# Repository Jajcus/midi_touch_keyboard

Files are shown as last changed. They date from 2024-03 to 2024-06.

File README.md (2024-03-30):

# MIDI Touch Keyboard

**Disclaimer**: this is a one-time personal hobby project. Shared as-is. Work
in progress. **Use at your own risk**, if at all.

This project is a device that lets you play MIDI synthesizer by touching
conducting surfaces, like fruits or vegetables.

It has 16 inputs (a bit over an octave), standard DIN-5 MIDI output and USB
MIDI interface. Additional controls include 'calibrate' button and a
'sensitivity' potentiometer.

A LED strip provides additional feedback displaying key state in piano-like layout.

assembled and connected
device with fruits and veggies connected

## Working principle

Each 'input' is a simple capacitive sensor. Touching it either significantly
increases input capacitance or lowers its resistance to the device's ground. In
both cases this causes increase in the time constant of an RC circuit monitored
by a microcontroller.

The microcontroller charges the capacitance of the sensor circuit in short
intervals and checks if it discharges before a specific time. If it does, then
the input is open if it does not, it means the sensor has been touched.

The time to wait for discharging is determined through a calibration process
and the sensitivity potentiometer. The calibration process just measures the discharge times,
and collects maximum and minimum values measured, to roughly find the threshold
range. This assumes that at least one of the sensors has been touched during calibration.
Then the sensitivity knob can be used to set threshold within this range.

## Circuit design

The heart of the device is a Raspberry Pi Pico board. Cheap and powerful enough.

The sensor inputs are built using two resistors and a capacitor connected do
the microcontroller general-purpose IO pins. Values of those components has
been chosen experimentally to get quick and precise-enough measurements.

One pin is used to drive MIDI output. That is a standard circuit from the MIDI
1.0 specification using a transistor as the current loop switch (with a
Schottky diode for sharper edges).

Another pin drives addressable LED strip (WS2812B). Again, a transistor with a
Schottky diode is used to drive 5V data line here.

Two pins are used for button (actually only one used at the moment).

One ADC pin is connected to the sensitivity potentiometer. Another ADC pin is
connected to the sensors connector, so it can be used for detection of a device
connected there (in case I make one).

There is also an additional DC input, in case the micro-USB on the Pico is not
enough, because why not.

circuit schematic

## Hardware realization

The device has been built on a single 'DIY' double-sided PCB, manufactured on a
small CNC engraver. Brass rivets are used for vias, otherwise no holes are
copper-plated. Most elements are surface mounted, 0603 size. The Raspberry Pi
Pico board is also surface-soldered to the main PCB, to keep overall low
profile (which the MIDI jack breaks anyway).

Sensor inputs are available via an angled 2x20 pin connector (like for an
old-style IDE HDD ribbon). Lower pins are all ground, sensors are on the upper
pins, starting from the third one. The last upper pin measures resistance to
the ground, for some auto-configuration capability in the future (not used now).

PCB layout is designed for my DIY constraints and the way I imagined the
complete device and is not suitable for most other fabrication processes.

The PCB design from KiCAD has been exported to Gerber files which would first
be converted to gcode by [pcb2gcode](https://github.com/pcb2gcode/pcb2gcode)
and then that gcode would be further processed by my
[postprocess.py](kicad/postprocess.py) script, for easier use with
[bCNC](https://github.com/vlachoudis/bCNC). Then couple of attempts and many
hours with the CNC machine and the PCB was ready for soldering. No soldermask,
unfortunately.

Even without the soldermask and with the small SMD components soldering was not
very hard. There was just a couple places that needed a do-over and proper
cleanup (the sensor circuit is quite sensitive to bad isolation, as 10 megaohm
resistors are used there).

The holes were drilled a bit to shallow, but that was not hard to fix, either.

PCB tracks close up
PCB holes top view
PCB holes bottom view
via rivets top view
small parts soldered

## Firmware

The firmware is written in Rust, using the marvelous
[Embassy](https://embassy.dev/) framework. Nothing fancy otherwise.

One CPU core is dedicated for reading the sensors and UI inputs and basic
key-on/key-off logic. The other core does MIDI I/O over serial and USB.
Components communicate by passing messages via Embassy channels.

The LED strip programming uses Raspberry Pi Pico's PIO (programmable I/O), so
no bit-banging in CPU time is needed.

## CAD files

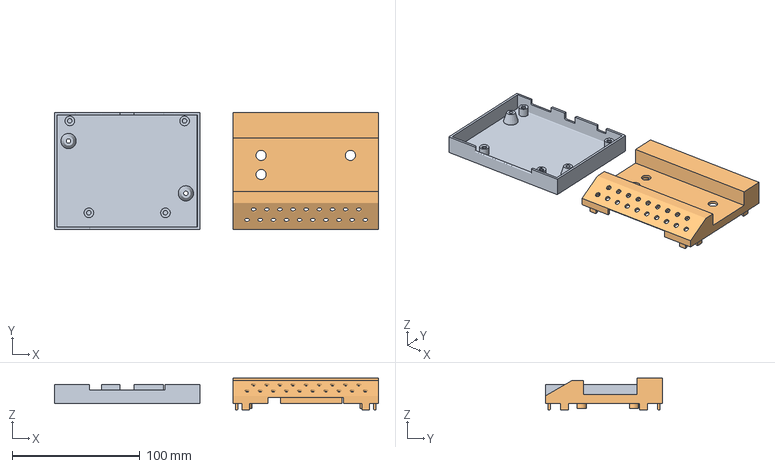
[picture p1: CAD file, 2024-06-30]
case/tk_case_3dprint.FCStd
254.0 x 92.0 x 25.0 mm
Case Bottom (Meshed)
Case Top (Meshed)

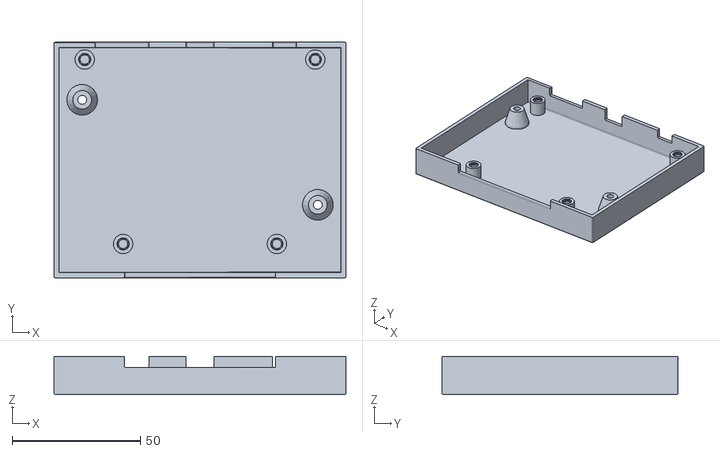
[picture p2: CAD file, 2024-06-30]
case/tk_case_bottom.stl
114.0 x 92.0 x 15.0

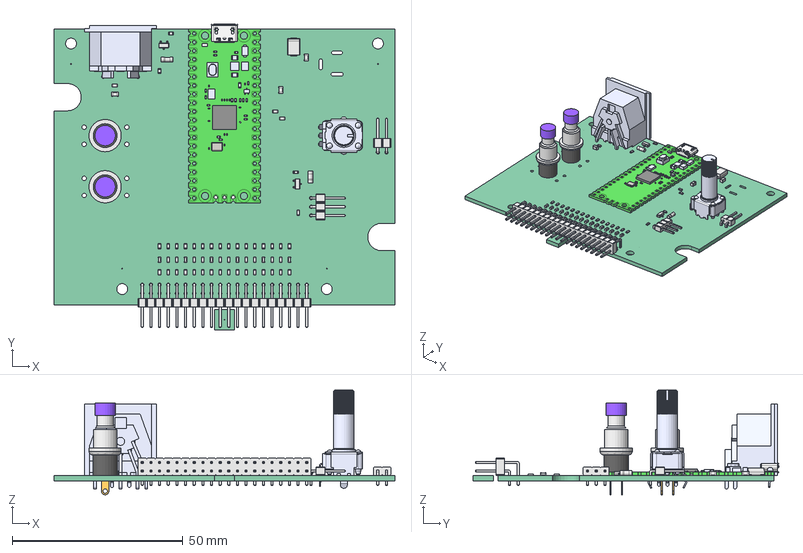
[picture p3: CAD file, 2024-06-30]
case/touch_keyboard_pcb.FCStd
100.0 x 89.7 x 30.7 mm
Pcb_1056
R33_R_0603_1608Metric_b52117b7a5b0 x 39
C5_C_0603_1608Metric_656f8ebd2c8c x 16
C18_C_0805_2012Metric_1ea8b0f87ad5 x 3
PCB, Raspberry Pi Pico-R3
MicroUSB Port, Raspberry Pi Pico-R3
MicroUSB Port, Raspberry Pi Pico-R004
MicroUSB Port, Raspberry Pi Pico-R005
MicroUSB Port, Raspberry Pi Pico-R006
MicroUSB Port, Raspberry Pi Pico-R007
MicroUSB Port, Raspberry Pi Pico-R008
MicroUSB Port, Raspberry Pi Pico-R009
RP2040 Microcontroller, Raspberry Pi Pico-R3
SW1, Tact Switch, Raspberry Pi Pico-R3
D1, Diode, Schottky, Raspberry Pi Pico-R3
D2, QSME-C194, LED, Raspberry Pi Pico-R3
L1, Inductor, Raspberry Pi Pico-R3
U2, RT6150B-33GQW, Buck Boost Converter, Raspberry Pi Pico-R3
U3, W25Q16JVUXIQ, Serial NOR Flash 16 Mbit, Raspberry Pi Pico-R3
Q1, MOSFET, DMG1012T, Raspberry Pi Pico-R3
X1, X12M000000S096, 12 Mhz Crystal Resonator, Raspberry Pi Pico-R3
SMD Resistor, Configurable, Raspberry Pi Pico-R3_R1
SMD Resistor, Configurable, Raspberry Pi Pico-R3_R002
SMD Resistor, Configurable, Raspberry Pi Pico-R3_R003
SMD Resistor, Configurable, Raspberry Pi Pico-R3_R2
SMD Resistor, Configurable, Raspberry Pi Pico-R3_R005
SMD Resistor, Configurable, Raspberry Pi Pico-R3_R006
SMD Resistor, Configurable, Raspberry Pi Pico-R3_R3
SMD Resistor, Configurable, Raspberry Pi Pico-R3_R008
SMD Resistor, Configurable, Raspberry Pi Pico-R3_R009
SMD Resistor, Configurable, Raspberry Pi Pico-R3_R4
SMD Resistor, Configurable, Raspberry Pi Pico-R3_R011
SMD Resistor, Configurable, Raspberry Pi Pico-R3_R012
SMD Resistor, Configurable, Raspberry Pi Pico-R3_R5
SMD Resistor, Configurable, Raspberry Pi Pico-R3_R014
SMD Resistor, Configurable, Raspberry Pi Pico-R3_R015
SMD Resistor, Configurable, Raspberry Pi Pico-R3_R6
SMD Resistor, Configurable, Raspberry Pi Pico-R3_R017
SMD Resistor, Configurable, Raspberry Pi Pico-R3_R018
SMD Resistor, Configurable, Raspberry Pi Pico-R3_R7
SMD Resistor, Configurable, Raspberry Pi Pico-R3_R020
SMD Resistor, Configurable, Raspberry Pi Pico-R3_R021
SMD Resistor, Configurable, Raspberry Pi Pico-R3_R8
SMD Resistor, Configurable, Raspberry Pi Pico-R3_R023
SMD Resistor, Configurable, Raspberry Pi Pico-R3_R024
SMD Resistor, Configurable, Raspberry Pi Pico-R3_R9
SMD Resistor, Configurable, Raspberry Pi Pico-R3_R026
SMD Resistor, Configurable, Raspberry Pi Pico-R3_R027
SMD Resistor, Configurable, Raspberry Pi Pico-R3_R10
SMD Resistor, Configurable, Raspberry Pi Pico-R3_R029
SMD Resistor, Configurable, Raspberry Pi Pico-R3_R030
SMD Resistor, Configurable, Raspberry Pi Pico-R3_R11
SMD Resistor, Configurable, Raspberry Pi Pico-R3_R032
SMD Resistor, Configurable, Raspberry Pi Pico-R3_R033
SMD Resistor, Configurable, Raspberry Pi Pico-R3_R12
SMD Resistor, Configurable, Raspberry Pi Pico-R3_R035
SMD Resistor, Configurable, Raspberry Pi Pico-R3_R036
SMD Resistor, Configurable, Raspberry Pi Pico-R3_R13
SMD Resistor, Configurable, Raspberry Pi Pico-R3_R038
SMD Resistor, Configurable, Raspberry Pi Pico-R3_R039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

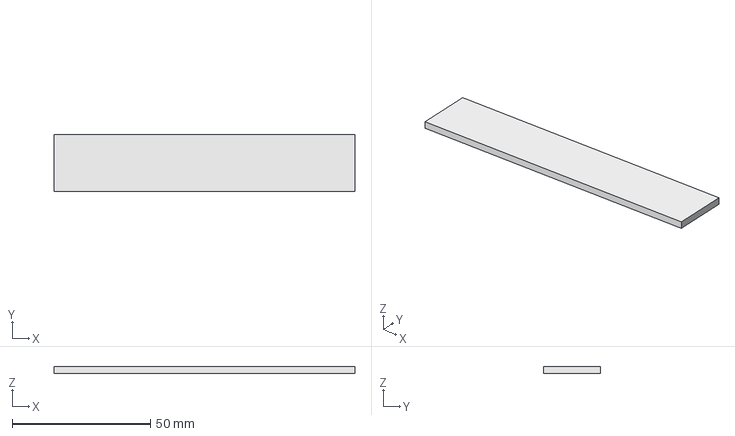
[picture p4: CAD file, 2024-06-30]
case/touch_keyboard_led_strip.FCStd
109.0 x 20.5 x 2.50 mm

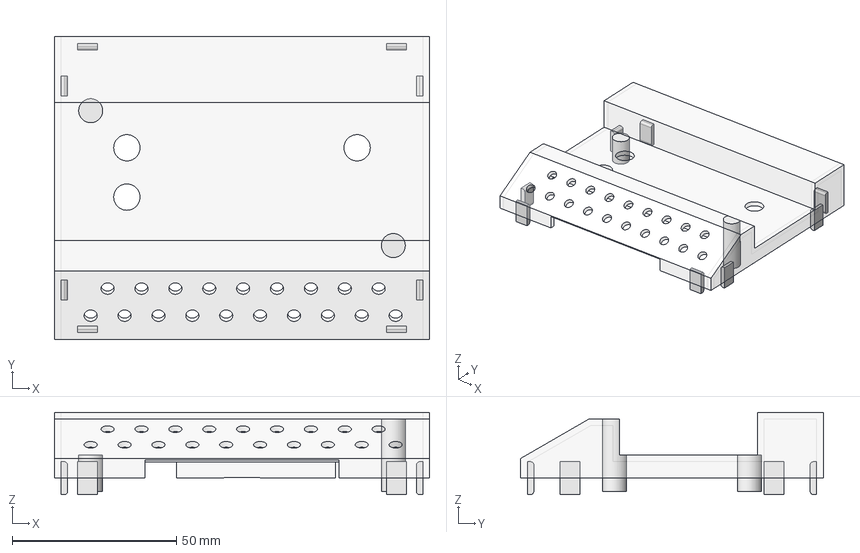
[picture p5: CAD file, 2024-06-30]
case/touch_keyboard_case_top.FCStd
114.0 x 92.0 x 25.0 mm
Case Top Body
Post1
Post2
Tab1
Tab2
Tab3
Tab4
Tab5
Tab6
Tab7
Tab8

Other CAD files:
case/touch_keyboard_case.FCStd
case/touch_keyboard_case_bottom.FCStd
case/tk_case_top.stl

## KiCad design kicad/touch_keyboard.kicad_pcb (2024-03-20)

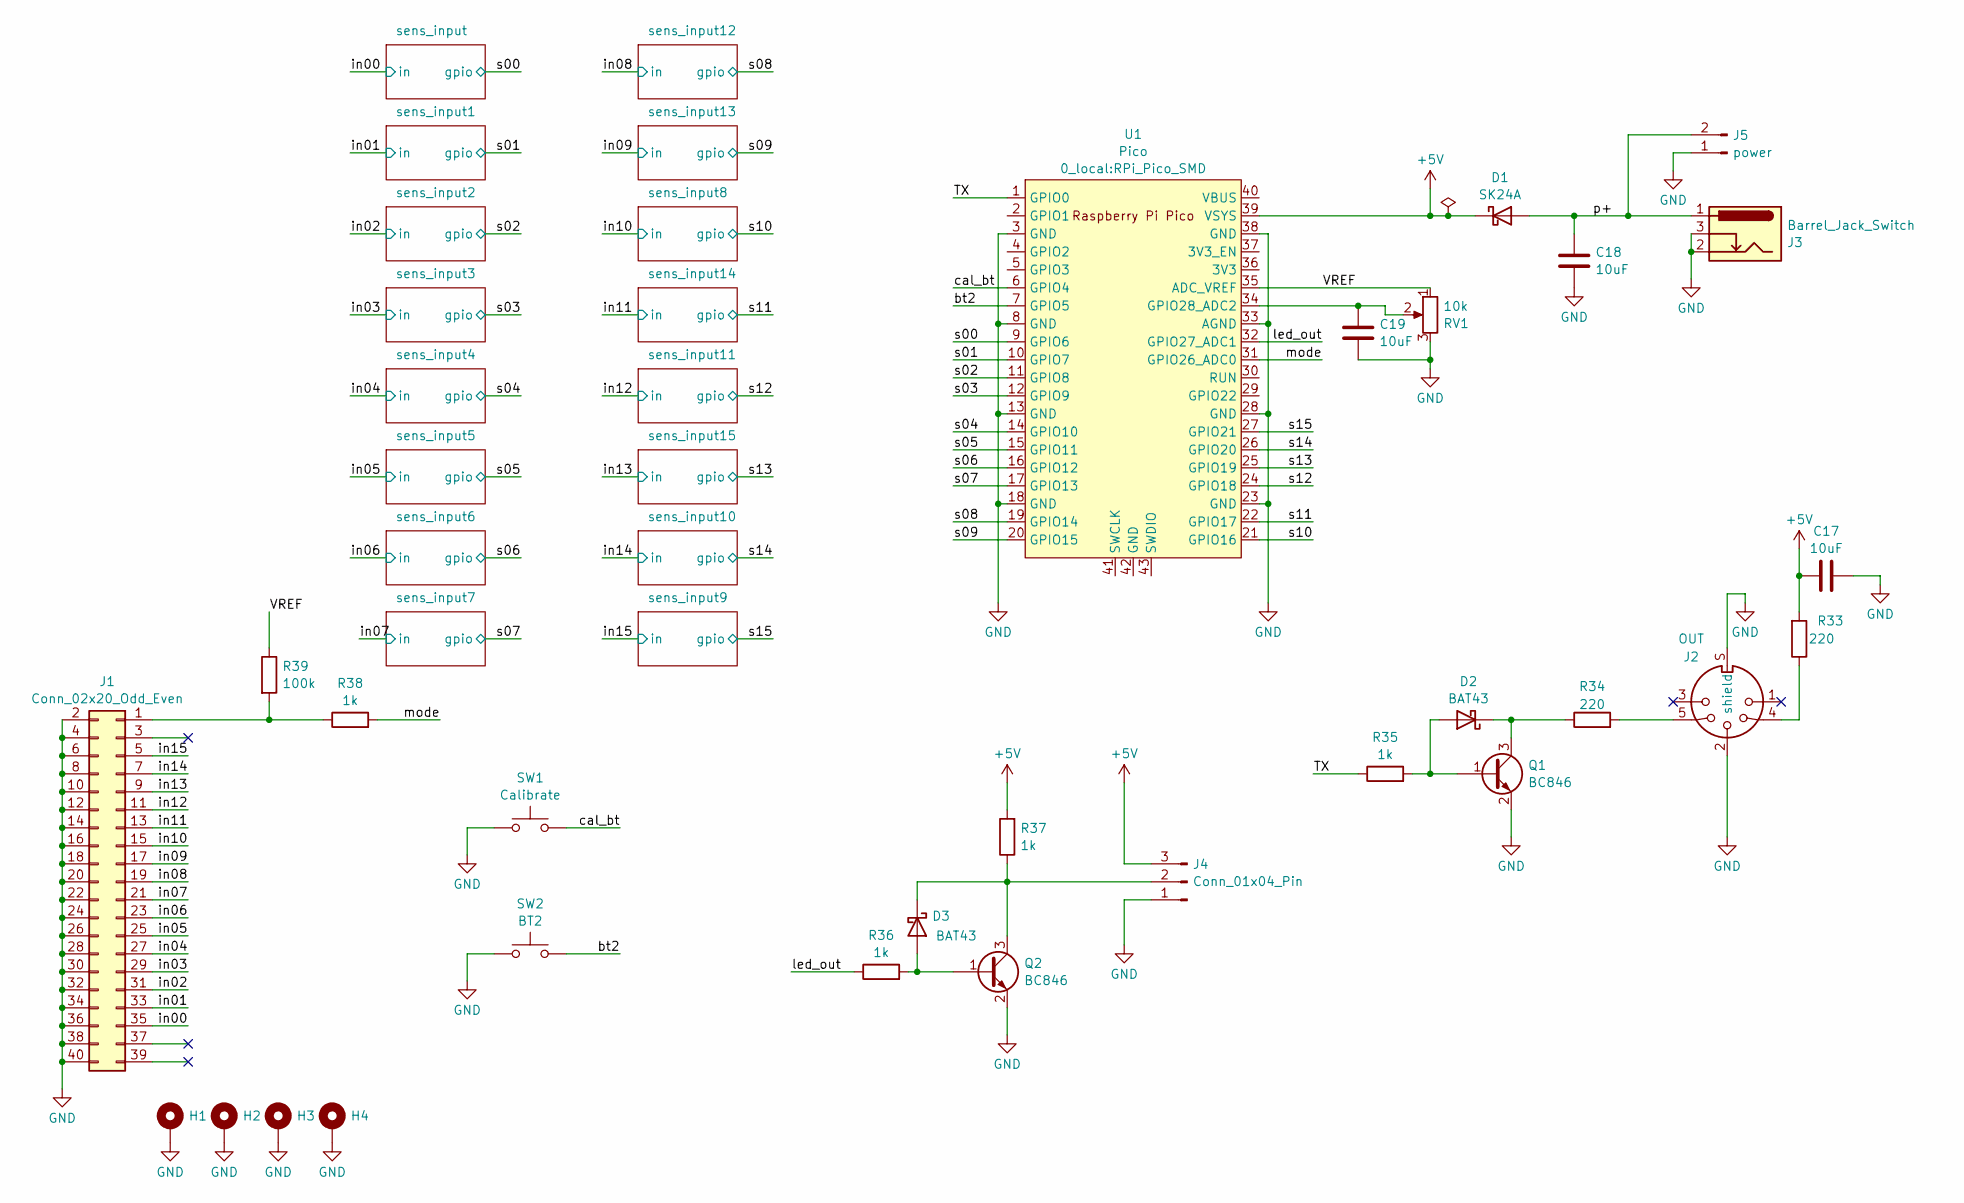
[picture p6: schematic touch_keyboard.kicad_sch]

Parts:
C17, C18, C19: 10uF; C_0805_2012Metric
D1: SK24A; D_SMA-SMB_Universal_Handsoldering
D2, D3: BAT43; D_MiniMELF
H1, H2, H3, H4: MountingHole_Pad; MountingHole_3.2mm_M3_DIN965_Pad
J1: Conn_02x20_Odd_Even; PinHeader_2x20_P2.54mm_Horizontal
J2: OUT; DIN_5
J3: Barrel_Jack_Switch; BarrelJack_CUI_PJ-063AH_Horizontal
J4: Conn_01x04_Pin; PinHeader_1x03_P2.54mm_Horizontal
J5: power; PinHeader_1x02_P2.54mm_Horizontal
Q1, Q2: BC846; SOT-23
R33, R34: 220; R_0603_1608Metric; MPN C22962
R35, R36, R37, R38: 1k; R_0603_1608Metric; MPN C22962
R39: 100k; R_0603_1608Metric; MPN C22962
RV1: 10k; Potentiometer_Bourns_PTV09A-1_Single_Vertical
SW1: Calibrate; Button
SW2: BT2; Button
U1: Pico; RPi_Pico_SMD

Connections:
+5V: C17.1, D1.1 (K), J4.3, R33.2, R37.2, U1.39 (VSYS)
/TX: R35.1, U1.1 (GPIO0)
/VREF: R39.1, RV1.1, U1.35 (ADC_VREF)
/bt2: SW2.2, U1.7 (GPIO5)
/cal_bt: SW1.2, U1.6 (GPIO4)
/in00: J1.35; also elsewhere on the board
/in01: J1.33; also elsewhere on the board
/in02: J1.31; also elsewhere on the board
/in03: J1.29; also elsewhere on the board
/in04: J1.27; also elsewhere on the board
/in05: J1.25; also elsewhere on the board
/in06: J1.23; also elsewhere on the board
/in07: J1.21; also elsewhere on the board
/in08: J1.19; also elsewhere on the board
/in09: J1.17; also elsewhere on the board
/in10: J1.15; also elsewhere on the board
/in11: J1.13; also elsewhere on the board
/in12: J1.11; also elsewhere on the board
/in13: J1.9; also elsewhere on the board
/in14: J1.7; also elsewhere on the board
/in15: J1.5; also elsewhere on the board
/led_out: R36.1, U1.32 (GPIO27_ADC1)
/mode: R38.2, U1.31 (GPIO26_ADC0)
/p+: C18.2, D1.2 (A), J3.1, J5.2
/s00: U1.9 (GPIO6); also elsewhere on the board
/s01: U1.10 (GPIO7); also elsewhere on the board
/s02: U1.11 (GPIO8); also elsewhere on the board
/s03: U1.12 (GPIO9); also elsewhere on the board
/s04: U1.14 (GPIO10); also elsewhere on the board
/s05: U1.15 (GPIO11); also elsewhere on the board
/s06: U1.16 (GPIO12); also elsewhere on the board
/s07: U1.17 (GPIO13); also elsewhere on the board
/s08: U1.19 (GPIO14); also elsewhere on the board
/s09: U1.20 (GPIO15); also elsewhere on the board
/s10: U1.21 (GPIO16); also elsewhere on the board
/s11: U1.22 (GPIO17); also elsewhere on the board
/s12: U1.24 (GPIO18); also elsewhere on the board
/s13: U1.25 (GPIO19); also elsewhere on the board
/s14: U1.26 (GPIO20); also elsewhere on the board
/s15: U1.27 (GPIO21); also elsewhere on the board
GND: C17.2, C18.1, C19.1, H1.1, H2.1, H3.1, H4.1, J1.2, J1.4, J1.6, J1.8, J1.10, J1.12, J1.14, J1.16, J1.18, J1.20, J1.22, J1.24, J1.26, J1.28, J1.30, J1.32, J1.34, J1.36, J1.38, J1.40, J2.2, J2.S (shield), J3.2, J3.3, J4.1, J5.1, Q1.2 (E), Q2.2 (E), RV1.3, SW1.1, SW2.1, U1.3 (GND), U1.8 (GND), U1.13 (GND), U1.18 (GND), U1.23 (GND), U1.28 (GND), U1.33 (AGND), U1.38 (GND); also elsewhere on the board
unnamed: D2.2 (A), Q1.1 (B), R35.2
unnamed: D2.1 (K), Q1.3 (C), R34.1
unnamed: D3.2 (A), Q2.1 (B), R36.2
unnamed: D3.1 (K), J4.2, Q2.3 (C), R37.1
unnamed: J1.1, R38.1, R39.2
unnamed: J2.4, R33.1
unnamed: J2.5, R34.2
unnamed: C19.2, RV1.2, U1.34 (GPIO28_ADC2)

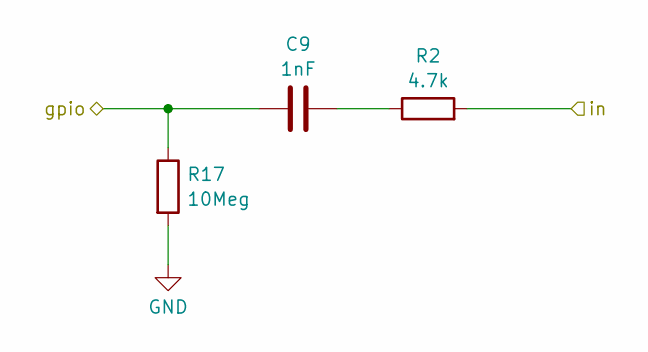
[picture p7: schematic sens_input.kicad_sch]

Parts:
C9: 1nF; C_0603_1608Metric
R2: 4.7k; R_0603_1608Metric
R17: 10Meg; R_0603_1608Metric

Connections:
/in00: R2.2; also elsewhere on the board
/s08: C9.1, R17.1; also elsewhere on the board
GND: R17.2; also elsewhere on the board

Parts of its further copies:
C1, C2, C3, C4, C5, C6, C7, C8, C10, C11, C12, C13, C14, C15, C16: 1nF; C_0603_1608Metric
R1, R3, R5, R7, R9, R11, R13, R15, R19, R21, R23, R25, R27, R29, R31: 10Meg; R_0603_1608Metric
R4, R6, R8, R10, R12, R14, R16, R18, R20, R22, R24, R26, R28, R30, R32: 4.7k; R_0603_1608Metric

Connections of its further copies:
/in01: R4.2; also elsewhere on the board
/in02: R6.2; also elsewhere on the board
/in03: R8.2; also elsewhere on the board
/in04: R10.2; also elsewhere on the board
/in05: R12.2; also elsewhere on the board
/in06: R14.2; also elsewhere on the board
/in07: R16.2; also elsewhere on the board
/in08: R18.2; also elsewhere on the board
/in09: R20.2; also elsewhere on the board
/in10: R22.2; also elsewhere on the board
/in11: R24.2; also elsewhere on the board
/in12: R26.2; also elsewhere on the board
/in13: R28.2; also elsewhere on the board
/in14: R30.2; also elsewhere on the board
/in15: R32.2; also elsewhere on the board
/s00: C1.1, R1.1; also elsewhere on the board
/s01: C2.1, R3.1; also elsewhere on the board
/s02: C3.1, R5.1; also elsewhere on the board
/s03: C4.1, R7.1; also elsewhere on the board
/s04: C5.1, R9.1; also elsewhere on the board
/s05: C6.1, R11.1; also elsewhere on the board
/s06: C7.1, R13.1; also elsewhere on the board
/s07: C8.1, R15.1; also elsewhere on the board
/s09: C10.1, R19.1; also elsewhere on the board
/s10: C11.1, R21.1; also elsewhere on the board
/s11: C12.1, R23.1; also elsewhere on the board
/s12: C13.1, R25.1; also elsewhere on the board
/s13: C14.1, R27.1; also elsewhere on the board
/s14: C15.1, R29.1; also elsewhere on the board
/s15: C16.1, R31.1; also elsewhere on the board
GND: R1.2, R3.2, R5.2, R7.2, R9.2, R11.2, R13.2, R15.2, R19.2, R21.2, R23.2, R25.2, R27.2, R29.2, R31.2; also elsewhere on the board
unnamed: C2.2, R4.1
unnamed: C3.2, R6.1
unnamed: C4.2, R8.1
unnamed: C5.2, R10.1
unnamed: C6.2, R12.1
unnamed: C7.2, R14.1
unnamed: C8.2, R16.1
unnamed: C10.2, R20.1
unnamed: C11.2, R22.1
unnamed: C12.2, R24.1
unnamed: C13.2, R26.1
unnamed: C14.2, R28.1
unnamed: C15.2, R30.1
unnamed: C16.2, R32.1

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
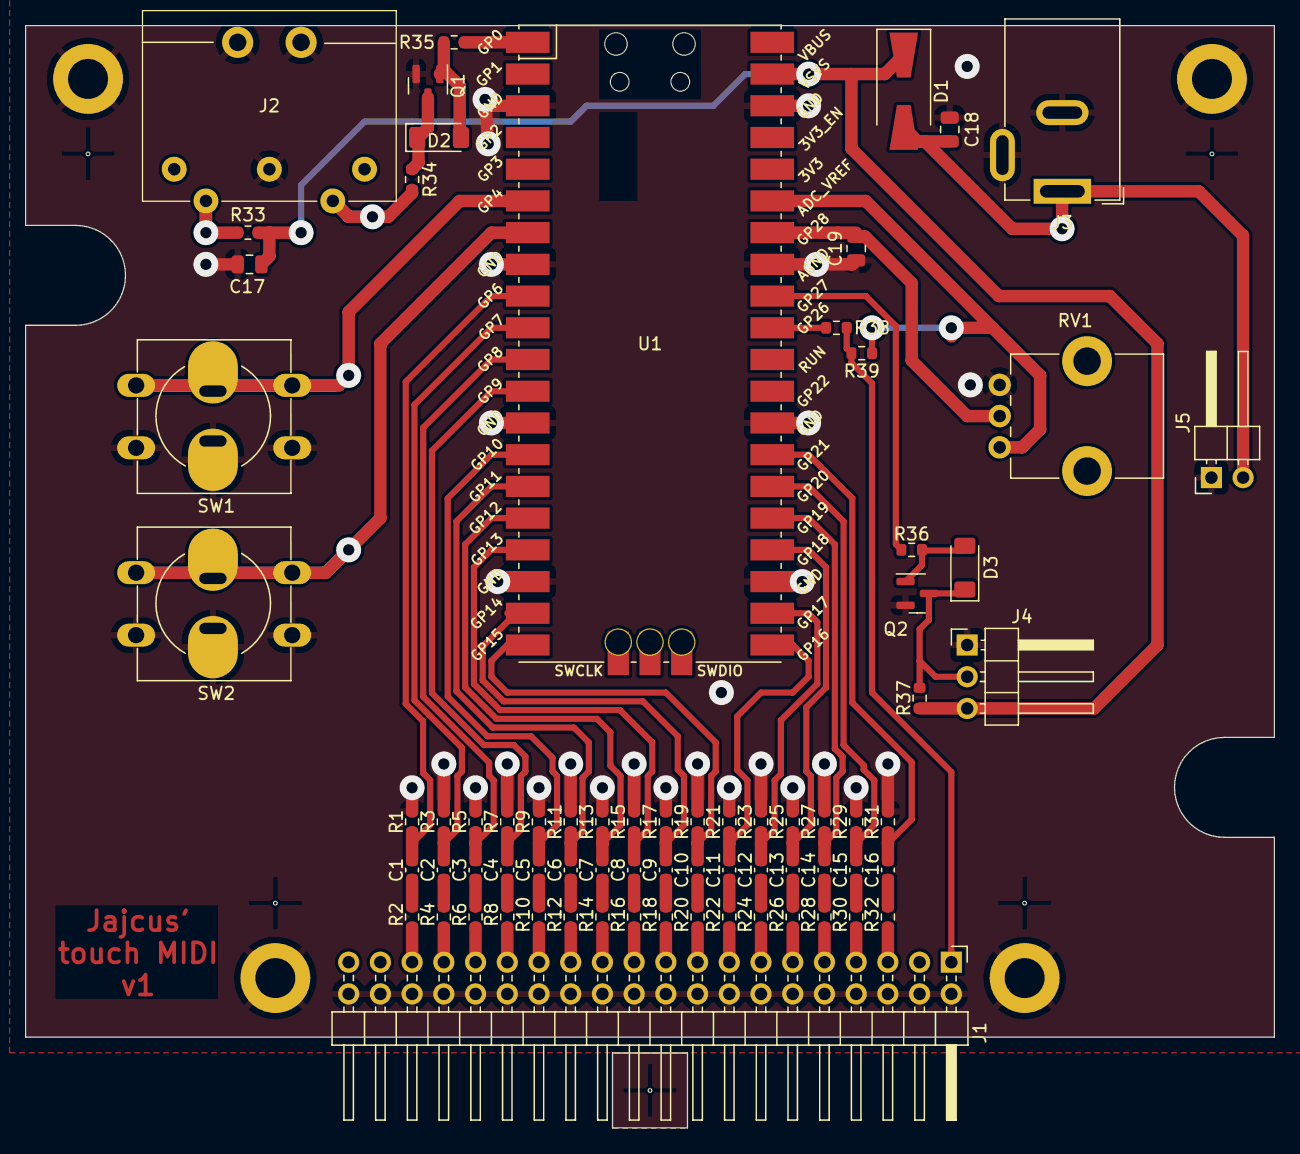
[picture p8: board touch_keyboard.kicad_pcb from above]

Board: 2 copper layers, 100.0 x 88.3 mm, 76 parts (0 on the bottom side), 65 nets.

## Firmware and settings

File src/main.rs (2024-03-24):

//! This example test the RP Pico on board LED.
//!
//! It does not work with the RP Pico W board. See wifi_blinky.rs.

#![no_std]
#![no_main]

use core::ptr::addr_of_mut;
use defmt::{unreachable, *};
use embassy_executor::Executor;
use embassy_futures::join::join3;
use embassy_rp::multicore::{spawn_core1, Stack};
use embassy_time::{Duration, Timer};
use static_cell::StaticCell;
use {defmt_rtt as _, panic_probe as _};

mod adc;
mod board;
mod button;
mod config;
mod midi;
mod serial_midi;
mod touch_sensors;
mod usb_midi;
mod ws2812b;

use crate::adc::{Adc, AdcValues};
use crate::button::Button;
use crate::config::*;
use crate::midi::{
    MidiChannel, MidiChannelMC, MidiChannelMCReceiver, MidiChannelMCSender, MidiMsg,
};
use crate::serial_midi::SerialMidi;
use crate::touch_sensors::{CalibrationStatus, TouchSensorStatus, TouchSensors};
use crate::usb_midi::UsbMidi;
use crate::ws2812b::WS2812B;

static EXECUTOR0: StaticCell<Executor> = StaticCell::new();
static EXECUTOR1: StaticCell<Executor> = StaticCell::new();
static mut CORE1_STACK: Stack<102400> = Stack::new();

#[cortex_m_rt::entry]
fn main() -> ! {
    let p = embassy_rp::init(Default::default());
    let b = crate::board::init(p);

    let mut led = b.led_out;

    info!("Minimal duration: {}ms", Duration::MIN.as_micros());

    info!("led on!");
    led.set_high();

    static MIDI_CHANNEL: MidiChannelMC = MidiChannelMC::new();

    spawn_core1(
        b.core1_core,
        unsafe { &mut *addr_of_mut!(CORE1_STACK) },
        move || {
            let executor1 = EXECUTOR1.init(Executor::new());
            executor1
                .run(|spawner| unwrap!(spawner.spawn(core1_task(b.core1, MIDI_CHANNEL.receiver()))))
        },
    );

    let executor0 = EXECUTOR0.init(Executor::new());
    executor0.run(|spawner| unwrap!(spawner.spawn(core0_task(b.core0, MIDI_CHANNEL.sender()))))
}

#[embassy_executor::task]
async fn core0_task(b: crate::board::Core0Pers, midi_tx: MidiChannelMCSender<'static>) -> ! {
    let leds = WS2812B::new(b.leds_pio, b.leds_pin);
    let sensors = TouchSensors::new(b.sensor_pins);

    let adc_values = AdcValues::new();
    let button = Button::new(b.button_in);
    let adc = Adc::new(b.adc, b.adc_pins, &adc_values).unwrap();

    let bt_task = button.task();
    let adc_task = adc.task();

    let main_task = measure_task(leds, sensors, &button, &adc_values, midi_tx);

    join3(main_task, bt_task, adc_task).await;

    unreachable!();
}

#[embassy_executor::task]
async fn core1_task(b: crate::board::Core1Pers, midi_c0_rx: MidiChannelMCReceiver<'static>) -> ! {
    let serial_midi_channel = MidiChannel::new();
    let serial_midi_tx = serial_midi_channel.sender();
    let usb_midi_channel = MidiChannel::new();
    let usb_midi_tx = usb_midi_channel.sender();
    let mut serial_midi =
        SerialMidi::new(b.midi_uart, b.midi_tx_pin, serial_midi_channel.receiver());
    let mut usb_midi = UsbMidi::new(b.midi_usb, usb_midi_channel.receiver());
    let serial_midi_task = serial_midi.task();
    let usb_midi_task = usb_midi.task();

    let midi_router_task = async {
        loop {
            let msg = midi_c0_rx.receive().await;
            serial_midi_tx.try_send(msg).ok();
            usb_midi_tx.try_send(msg).ok();
        }
    };

    join3(midi_router_task, serial_midi_task, usb_midi_task).await;

    unreachable!();
}

async fn measure_task<'a>(
    mut leds: WS2812B,
    mut sensors: TouchSensors<'a>,
    button: &Button<'a>,
    adc_values: &'a AdcValues,
    midi_tx: MidiChannelMCSender<'a>,
) {
    let mut colors = [COL_UNUSED; NUM_LEDS];

    for i in 0..NUM_LEDS {
        colors[i] = WELCOME_COLORS[i];
        leds.write(&colors).await;
        Timer::after_millis(50).await;
    }
    for i in 0..NUM_LEDS {
        colors[i] = 0;
        leds.write(&colors).await;
        Timer::after_millis(50).await;
    }

    loop {
        colors = [COL_CAL_NA; NUM_LEDS];
        leds.write(&colors).await;

        sensors.calibrate_start().await;
        let mut cycle = 0;
        while !button.was_pressed() {
            let calib = sensors.calibrate_step().await;
            info!("{}", calib);
            info!("sens: {}%", adc_values.get_value(0, 100));
            for (i, which_led) in SENSOR_TO_LED.iter().enumerate().take(NUM_SENSORS) {
                let color = match which_led {
                    None => {
                        continue;
                    }
                    Some(led) => &mut colors[*led],
                };
                let status = calib.pins[i].status;
                *color = match status {
                    CalibrationStatus::NA => COL_CAL_NA,
                    CalibrationStatus::Ok => COL_CAL_OK,
                    CalibrationStatus::Bad => COL_CAL_BAD,
                } * if i == cycle { 4 } else { 1 };
            }
            leds.write(&colors).await;
            cycle = (cycle + 1) % NUM_SENSORS;
            Timer::after_millis(100).await;
        }
        let result = sensors.calibrate_stop().await;
        if result.status != CalibrationStatus::Ok {
            continue;
        }

        colors = [COL_UNUSED; NUM_LEDS];
        for (i, which_led) in SENSOR_TO_LED.iter().enumerate().take(NUM_SENSORS) {
            let color = match which_led {
                None => {
                    continue;
                }
                Some(led) => &mut colors[*led],
            };
            let status = result.pins[i].status;
            let piano_key = SENSOR_TO_PIANO_KEY[i];
            *color = match (status, piano_key) {
                (CalibrationStatus::NA, PianoKey::White) => COL_WHITE_OFF,
                (CalibrationStatus::NA, PianoKey::Black) => COL_BLACK_OFF,
                (CalibrationStatus::Ok, PianoKey::White) => COL_WHITE_OFF,
                (CalibrationStatus::Ok, PianoKey::Black) => COL_BLACK_OFF,
                (CalibrationStatus::Bad, _) => COL_BROKEN,
                (_, PianoKey::Missing) => COL_UNUSED,
            }
        }
        leds.write(&colors).await;

        let mut prev_status = [TouchSensorStatus::NA; NUM_SENSORS];
        while !button.was_pressed() {
            let sens = adc_values.get_value(0, 1000).unwrap_or(500);
            sensors.set_sensitivity(sens);
            let status = sensors.run().await;
            debug!("Status: {}", status);
            debug!("Previous: {}", prev_status);
            for (i, (prev, cur)) in prev_status.iter_mut().zip(status.iter()).enumerate() {
                if *cur == *prev {
                    continue;
                }
                match *cur {
                    TouchSensorStatus::NA => continue,
                    TouchSensorStatus::On => {
                        info!("Touched: {}", i);
                    }
                    TouchSensorStatus::Off => {
                        info!("Released: {}", i);
                    }
                };
                *prev = *cur;
                let piano_key = SENSOR_TO_PIANO_KEY[i];
                let color = match (*cur, piano_key) {
                    (TouchSensorStatus::Off, PianoKey::White) => COL_WHITE_OFF,
                    (TouchSensorStatus::Off, PianoKey::Black) => COL_BLACK_OFF,
                    (TouchSensorStatus::On, PianoKey::White) => COL_WHITE_ON,
                    (TouchSensorStatus::On, PianoKey::Black) => COL_BLACK_ON,
                    (_, PianoKey::Missing) => COL_UNUSED,
                    _ => unreachable!(),
                };
                let maybe_note_nr = if let Some(nr) = SENSOR_TO_NOTE[i] {
                    let note_nr = ROOT_NOTE + nr;
                    if note_nr >= 0 {
                        Some(note_nr)
                    } else {
                        None
                    }
                } else {
                    None
                };

                match (*cur, maybe_note_nr) {
                    (TouchSensorStatus::On, Some(note_nr)) => {
                        let msg = MidiMsg::NoteOn {
                            note: note_nr,
                            velocity: 64,
                        };
                        info!("Midi: {}", msg);
                        midi_tx.try_send(msg).ok(); // ignore error (buffer full)
                    }
                    (TouchSensorStatus::Off, Some(note_nr)) => {
                        let msg = MidiMsg::NoteOff {
                            note: note_nr,
                            velocity: 0,
                        };
                        info!("Midi: {}", msg);
                        midi_tx.send(msg).await; // wait until this note-off can be sent
                    }
                    _ => (),
                };
                if let Some(led) = SENSOR_TO_LED[i] {
                    colors[led] = color;
                    leds.write(&colors).await;
                }
            }
            Timer::after_millis(2).await;
        }
    }
}

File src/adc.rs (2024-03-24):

use embassy_rp::bind_interrupts;
use embassy_rp::gpio::Pull;
use embassy_rp::peripherals::ADC;
use embassy_rp::Peripheral;
use embassy_time::Timer;

use core::cell::Cell;

use crate::board::AdcPins;
use crate::config::ADC_INTERVAL;

bind_interrupts!(struct Irqs {
    ADC_IRQ_FIFO => embassy_rp::adc::InterruptHandler;
});

pub struct AdcValues {
    values: [Cell<u32>; 2],
}

pub struct Adc<'d> {
    adc: embassy_rp::adc::Adc<'d, embassy_rp::adc::Async>,
    channels: [embassy_rp::adc::Channel<'d>; 2],
    values: &'d AdcValues,
}

impl<'d> Adc<'d> {
    pub fn new(
        adc_per: impl Peripheral<P = ADC> + 'd,
        pins: AdcPins,
        values: &'d AdcValues,
    ) -> Result<Self, &'static str> {
        let config = embassy_rp::adc::Config::default();
        let adc = embassy_rp::adc::Adc::new(adc_per, Irqs, config);

        let channels = [
            embassy_rp::adc::Channel::new_pin(pins.0, Pull::None),
            embassy_rp::adc::Channel::new_pin(pins.1, Pull::None),
        ];

        Ok(Self {
            adc,
            channels,
            values,
        })
    }
    pub async fn task(mut self) -> ! {
        loop {
            for (i, ch) in self.channels.iter_mut().enumerate() {
                let value = self.adc.read(ch).await.unwrap_or(0).into();
                self.values.values[i].set(value);
            }
            Timer::after(ADC_INTERVAL).await;
        }
    }
}

impl Default for AdcValues {
    fn default() -> Self {
        Self::new()
    }
}

impl AdcValues {
    pub fn new() -> Self {
        Self {
            values: core::array::from_fn(|_| 0.into()),
        }
    }
    pub fn get_value(&self, input_number: usize, scale: u32) -> Result<u32, &'static str> {
        if input_number >= 2 {
            Err("Wrong input number")
        } else {
            let value = self.values[input_number].get();
            Ok(value * (scale + 1) / 4096)
        }
    }
}

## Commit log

2024-02-02 initial import
    work in progress
    [sens_input.kicad_sch, touch_keyboard.kicad_pcb, touch_keyboard.kicad_sch]
2024-02-02 sensing and LED improvements
2024-02-17 use 19 LEDs in piano keyboard layout
2024-02-27 circuit update
    [touch_keyboard.kicad_pcb, touch_keyboard.kicad_sch]
2024-02-27 adc code added
    will be used for sensitivity pot and 'mode' input pin
2024-03-15 map proper pin to the calibrate button
2024-03-20 update to the current version of the hardware
    includes pcb2gcode config and post-processing script
    [touch_keyboard.kicad_pcb, touch_keyboard.kicad_sch]
2024-03-24 usb_midi: collect multiple messages into the buffer
    for less latency / higher throughput… if anybody is able to play that fast ;)
2024-03-30 README: fix addressable LED model name
2024-06-30 case added (as built)
    [tk_case_3dprint.FCStd, tk_case_bottom.stl, tk_case_top.stl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]
